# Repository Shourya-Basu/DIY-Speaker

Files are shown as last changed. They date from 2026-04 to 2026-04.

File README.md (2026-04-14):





### Introduction 
Designed and validated an integrated Power Management Unit (PMU) from schematic to physical PCB, ensuring reliable energy storage and conversion for mobile device applications.

---

### Tech Stack

- Schematic – The blueprint stage where logical connections between components are defined using symbols, pins, and nets to create a functional electrical map.

- PCB Routing – The physical design process of laying down copper tracks (traces) on the board to connect components while adhering to design rules like clearance, trace width, and signal integrity.

- KiCad – An open-source EDA suite used for schematic capture and PCB layout, offering powerful tools for 3D visualization and Gerber file generation.
---

### Images

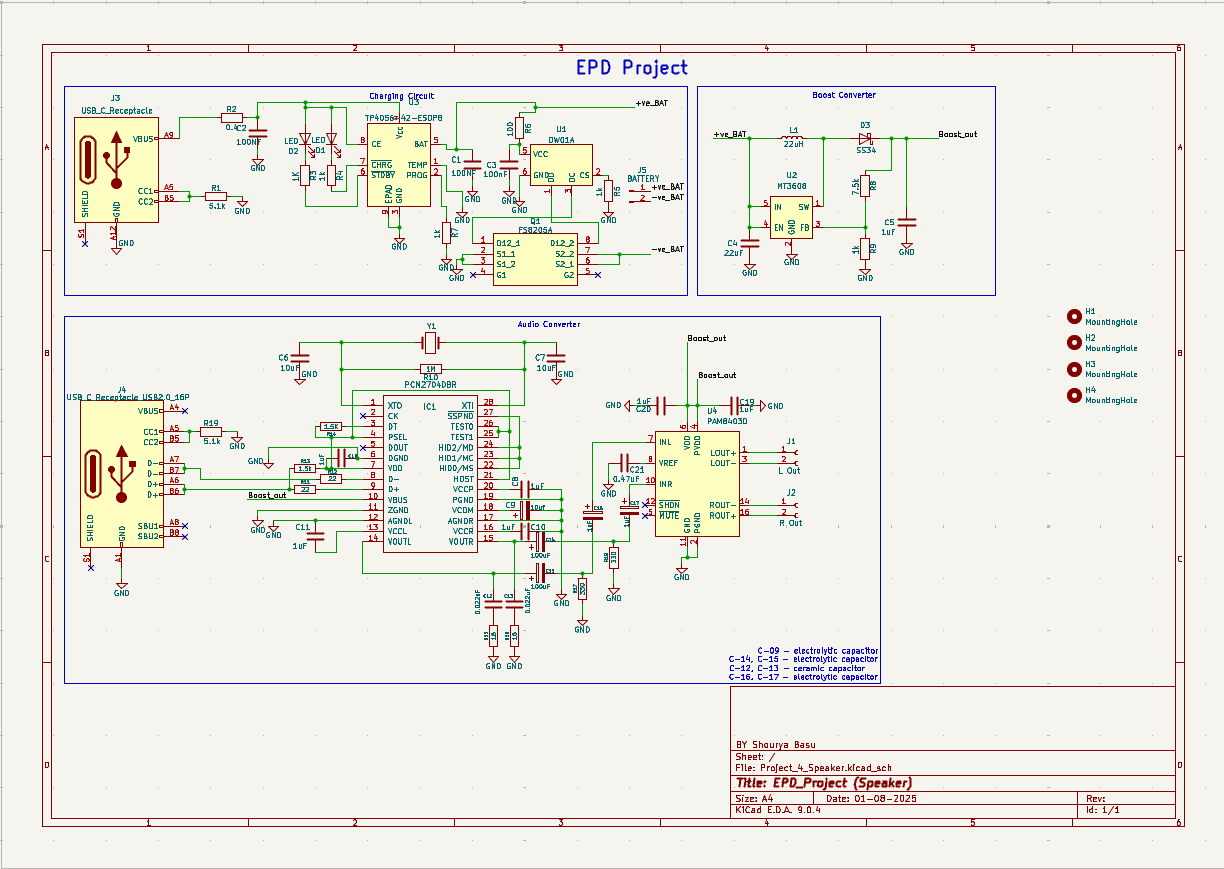
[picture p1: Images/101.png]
Schematic


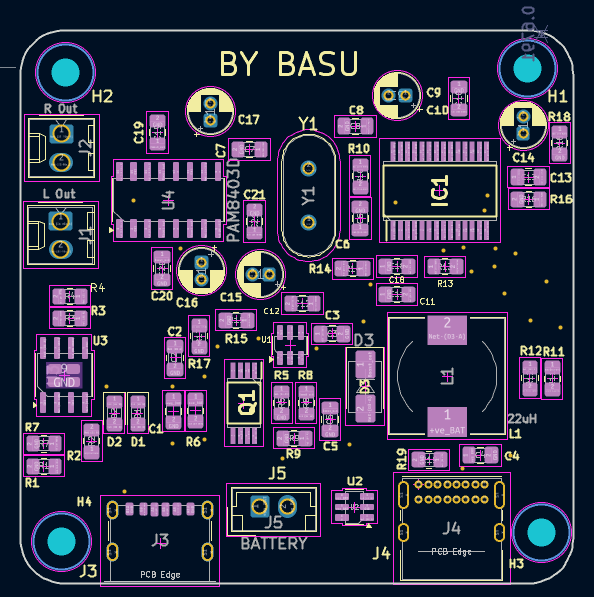
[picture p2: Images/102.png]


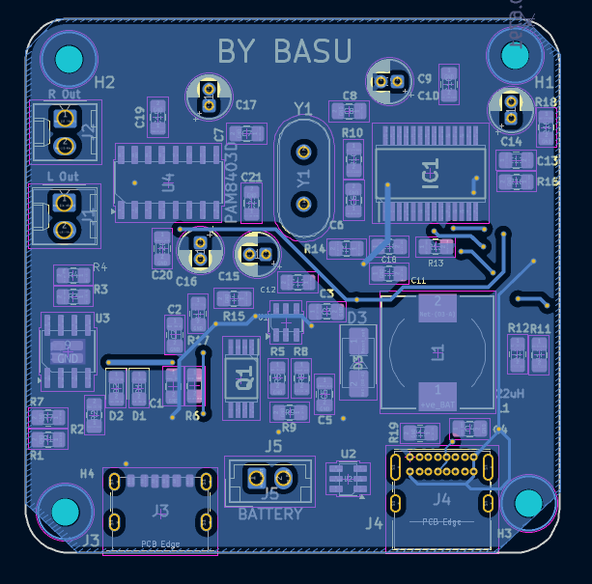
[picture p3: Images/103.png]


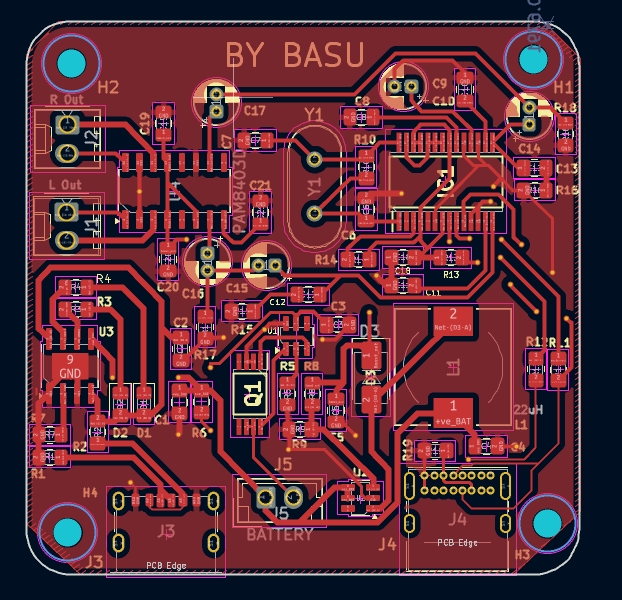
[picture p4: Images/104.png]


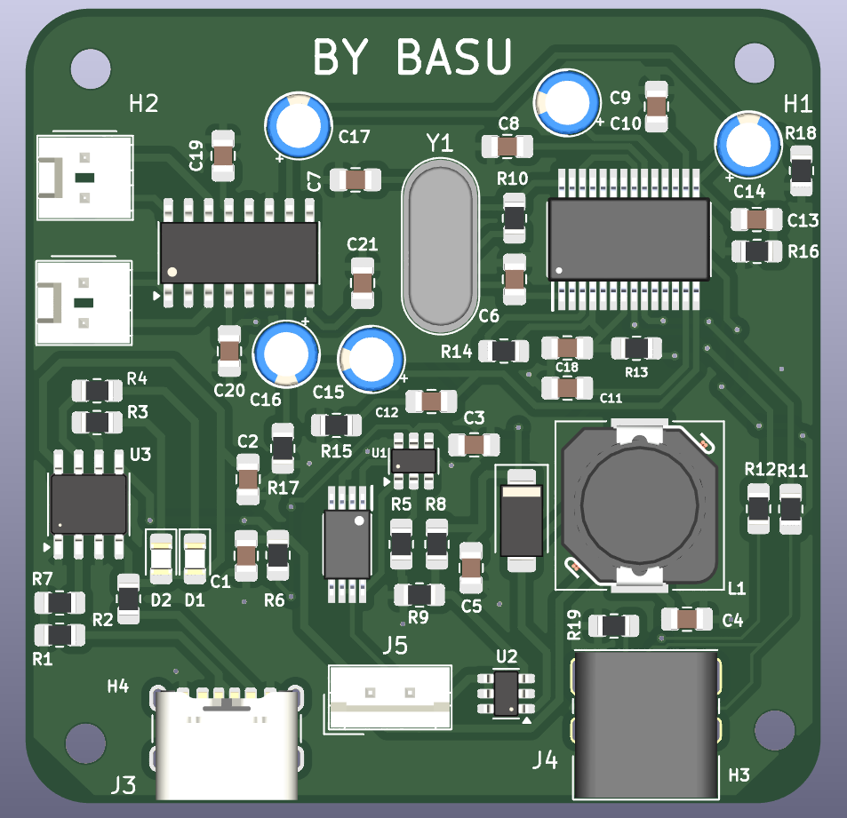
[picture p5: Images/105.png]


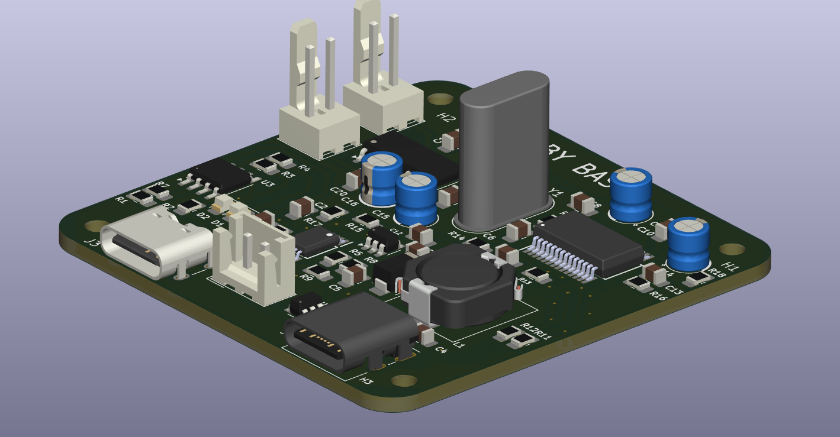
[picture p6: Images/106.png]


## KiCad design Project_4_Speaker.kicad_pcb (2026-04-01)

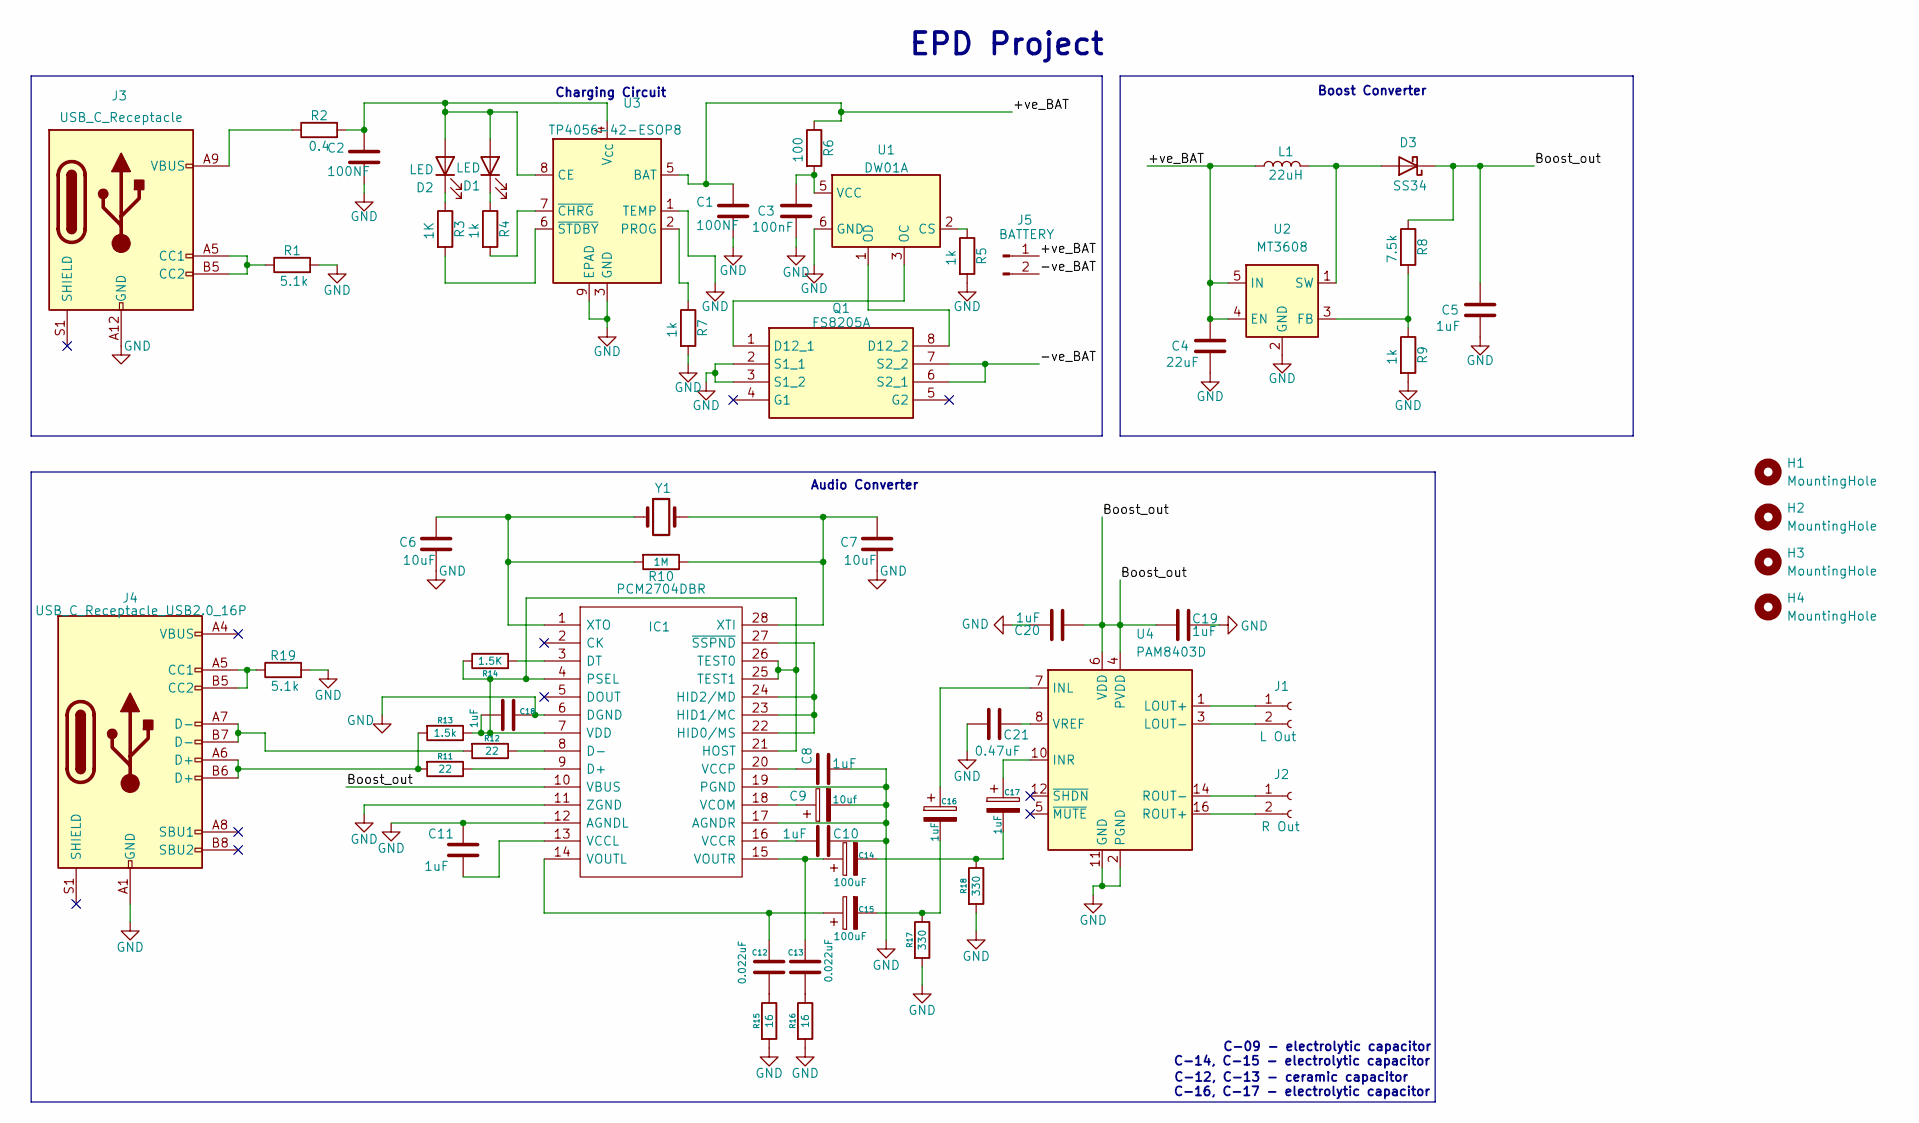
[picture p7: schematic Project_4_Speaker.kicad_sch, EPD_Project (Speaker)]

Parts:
C1, C2: 100NF; C_0805_2012Metric_Pad1.18x1.45mm_HandSolder
C3: 100nF; C_0805_2012Metric_Pad1.18x1.45mm_HandSolder
C4: 22uF; C_0805_2012Metric_Pad1.18x1.45mm_HandSolder
C5, C8, C10, C11, C18, C19, C20: 1uF; C_0805_2012Metric_Pad1.18x1.45mm_HandSolder
C6, C7: 10uF; C_0805_2012Metric_Pad1.18x1.45mm_HandSolder
C9: 10uf; CP_Radial_D4.0mm_P1.50mm
C12, C13: 0.022uF; C_0805_2012Metric_Pad1.18x1.45mm_HandSolder
C14, C15: 100uF; CP_Radial_D4.0mm_P1.50mm
C16, C17: 1uF; CP_Radial_D4.0mm_P1.50mm
C21: 0.47uF; C_0805_2012Metric_Pad1.18x1.45mm_HandSolder
D1, D2: LED; LED_0805_2012Metric_Pad1.15x1.40mm_HandSolder
D3: SS34; D_SMA
H1, H2, H3, H4: MountingHole; MountingHole_2.5mm
IC1: PCM2704DBR; SOP65P780X200-28N; Manufacturer_Part_Number PCM2704DBR; Mouser Part Number 595-PCM2704DBR
J1: L Out; Molex_KK-254_AE-6410-02A_1x02_P2.54mm_Vertical
J2: R Out; Molex_KK-254_AE-6410-02A_1x02_P2.54mm_Vertical
J3: USB_C_Receptacle; USB_C_Receptacle_GCT_USB4125-xx-x_6P_TopMnt_Horizontal
J4: USB_C_Receptacle_USB2.0_16P; USB_C_Receptacle_GCT_USB4085
J5: BATTERY; JST_EH_B2B-EH-A_1x02_P2.50mm_Vertical
L1: 22uH; L_10.4x10.4_H4.8
Q1: FS8205A; SOP65P640X120-8N; Manufacturer_Part_Number FS8205A
R1, R19: 5.1k; R_0805_2012Metric_Pad1.20x1.40mm_HandSolder
R2: 0.4; R_0805_2012Metric_Pad1.20x1.40mm_HandSolder
R3: 1K; R_0805_2012Metric_Pad1.20x1.40mm_HandSolder
R4, R5, R7, R9: 1k; R_0805_2012Metric_Pad1.20x1.40mm_HandSolder
R6: 100; R_0805_2012Metric_Pad1.20x1.40mm_HandSolder
R8: 7.5k; R_0805_2012Metric_Pad1.20x1.40mm_HandSolder
R10: 1M; R_0805_2012Metric_Pad1.20x1.40mm_HandSolder
R11, R12: 22; R_0805_2012Metric_Pad1.20x1.40mm_HandSolder
R13: 1.5k; R_0805_2012Metric_Pad1.20x1.40mm_HandSolder
R14: 1.5K; R_0805_2012Metric_Pad1.20x1.40mm_HandSolder
R15, R16: 16; R_0805_2012Metric_Pad1.20x1.40mm_HandSolder
R17, R18: 330; R_0805_2012Metric_Pad1.20x1.40mm_HandSolder
U1: DW01A; SOT-23-6
U2: MT3608; SOT-23-6
U3: TP4056-42-ESOP8; SOIC-8-1EP_3.9x4.9mm_P1.27mm_EP2.41x3.3mm
U4: PAM8403D; SO-16_3.9x9.9mm_P1.27mm
Y1: Crystal; Crystal_HC49-U_Vertical

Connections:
/+ve_BAT: C1.1, C4.1, J5.1, L1.1, R6.1, U2.4 (EN), U2.5 (IN), U3.5 (BAT)
/-ve_BAT: J5.2, Q1.6 (S2_1), Q1.7 (S2_2)
/Boost_out: C5.1, C19.1, C20.1, D3.1 (K), IC1.10 (VBUS), R8.1, U4.4 (PVDD), U4.6 (VDD), U4.13 (PVDD)
GND: C1.2, C2.2, C3.2, C4.2, C5.2, C6.2, C7.2, C8.2, C9.2, C10.1, C11.1, C18.1, C19.2, C20.2, C21.2, IC1.6 (DGND), IC1.11 (ZGND), IC1.12 (AGNDL), IC1.17 (AGNDR), IC1.19 (PGND), J3.A12 (GND), J3.B12 (GND), J4.A1 (GND), J4.A12 (GND), J4.B1 (GND), J4.B12 (GND), Q1.2 (S1_1), Q1.3 (S1_2), R1.2, R5.2, R7.2, R9.2, R15.2, R16.2, R17.2, R18.2, R19.2, U1.6 (GND), U2.2 (GND), U3.1 (TEMP), U3.3 (GND), U3.9 (EPAD), U4.2 (PGND), U4.11 (GND), U4.15 (PGND)
unnamed: C12.2, R15.1
unnamed: C13.2, R16.1
unnamed: C14.2, C17.2, R18.1
unnamed: C15.2, C16.2, R17.1
unnamed: C2.1, D1.2 (A), D2.2 (A), R2.2, U3.4 (V_{CC}), U3.8 (CE)
unnamed: D1.1 (K), R4.1
unnamed: D2.1 (K), R3.1
unnamed: D3.2 (A), L1.2, U2.1 (SW)
unnamed: IC1.9 (D+), R11.1
unnamed: IC1.8 (D-), R12.1
unnamed: IC1.3 (DT), R14.2
unnamed: IC1.22 (HID0/MS), IC1.23 (HID1/MC), IC1.24 (HID2/MD), IC1.27 (~SSPND)
unnamed: C18.2, IC1.4 (PSEL), IC1.7 (VDD), IC1.21 (HOST), IC1.25 (TEST1), IC1.26 (TEST0), R13.1, R14.1
unnamed: C11.2, IC1.13 (VCCL)
unnamed: C8.1, IC1.20 (VCCP)
unnamed: C10.2, IC1.16 (VCCR)
unnamed: C9.1, IC1.18 (VCOM)
unnamed: C12.1, C15.1, IC1.14 (VOUTL)
unnamed: C13.1, C14.1, IC1.15 (VOUTR)
unnamed: C7.1, IC1.28 (XTI), R10.1, Y1.2
unnamed: C6.1, IC1.1 (XTO), R10.2, Y1.1
unnamed: J1.1, U4.1 (LOUT+)
unnamed: J1.2, U4.3 (LOUT-)
unnamed: J2.1, U4.14 (ROUT-)
unnamed: J2.2, U4.16 (ROUT+)
unnamed: J3.A5 (CC1), J3.B5 (CC2), R1.1
unnamed: J3.A9 (VBUS), J3.B9 (VBUS), R2.1
unnamed: J4.A5 (CC1), J4.B5 (CC2), R19.1
unnamed: J4.A6 (D+), J4.B6 (D+), R11.2, R13.2
unnamed: J4.A7 (D-), J4.B7 (D-), R12.2
unnamed: Q1.1 (D12_1), U1.3 (OC)
unnamed: Q1.8 (D12_2), U1.1 (OD)
unnamed: R5.1, U1.2 (CS)
unnamed: C3.1, R6.2, U1.5 (VCC)
unnamed: R8.2, R9.1, U2.3 (FB)
unnamed: R7.1, U3.2 (PROG)
unnamed: R4.2, U3.7 (~CHRG)
unnamed: R3.2, U3.6 (~STDBY)
unnamed: C16.1, U4.7 (INL)
unnamed: C17.1, U4.10 (INR)
unnamed: C21.1, U4.8 (VREF)

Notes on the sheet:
C-12, C-13 - ceramic capacitor
Audio Converter
EPD Project
Charging Circuit
C-09 - electrolytic capacitor
C-14, C-15 - electrolytic capacitor
C-16, C-17 - electrolytic capacitor
Boost Converter

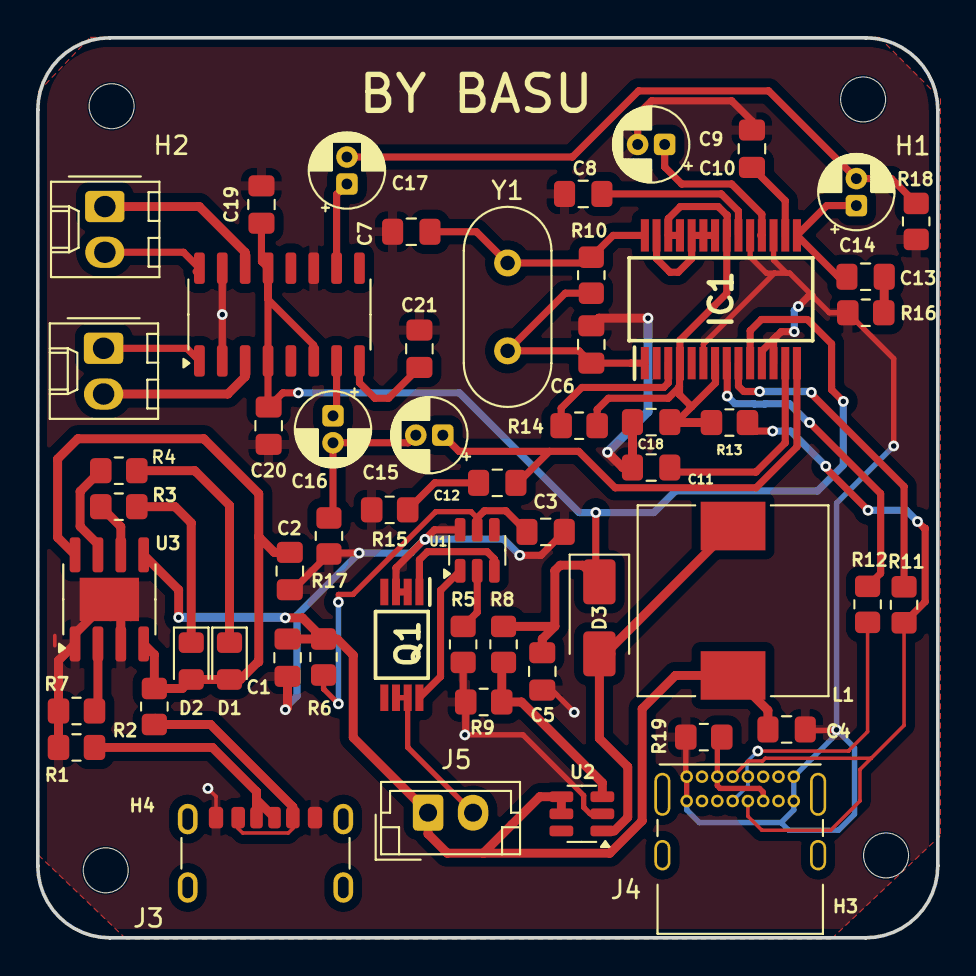
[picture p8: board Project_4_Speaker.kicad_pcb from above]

Board: 2 copper layers, 50.0 x 50.0 mm, 60 parts (0 on the bottom side), 45 nets.
